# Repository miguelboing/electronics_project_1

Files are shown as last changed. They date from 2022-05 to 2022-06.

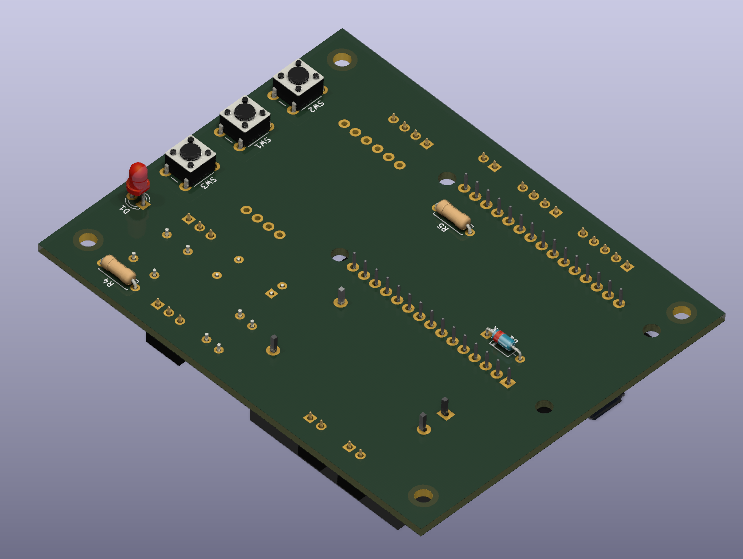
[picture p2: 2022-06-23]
hardware/botton_photo.png

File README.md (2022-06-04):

# _Electronics Project 1_

This project was created for the discipline EEL7801 - Dept. Electrical and Electronics Engineering.
The **Automatic Pet Feeder** was created to automate the routine of feeding your dog. It's hardware contains
a microcontroller ESP32 responsible for creating a routine of automatic feeding from a user configured time interval.

The firmware project uses the [ESPRESSIF framework](https://www.espressif.com/en/products/modules/esp32)
and all its tools.

## Firmware description

## Hardware description

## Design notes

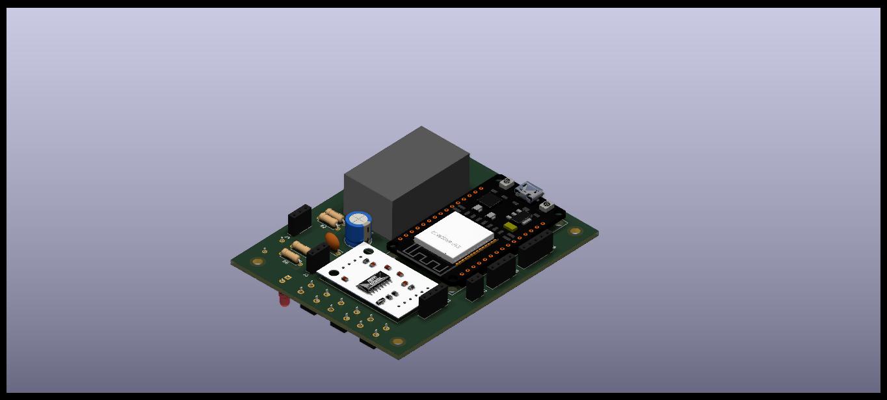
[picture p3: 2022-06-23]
hardware/alimentador automatico para pets.jpg

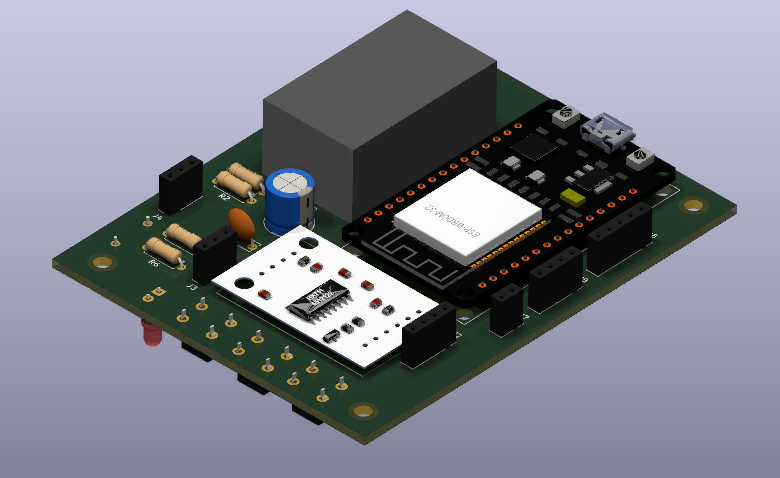
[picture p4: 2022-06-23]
hardware/top_photo.png

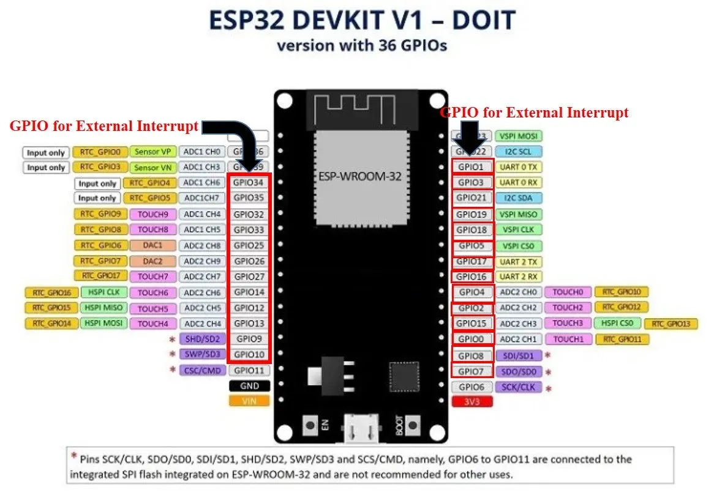
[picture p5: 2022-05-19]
documentation/ESP32-Interrupt-pins.webp

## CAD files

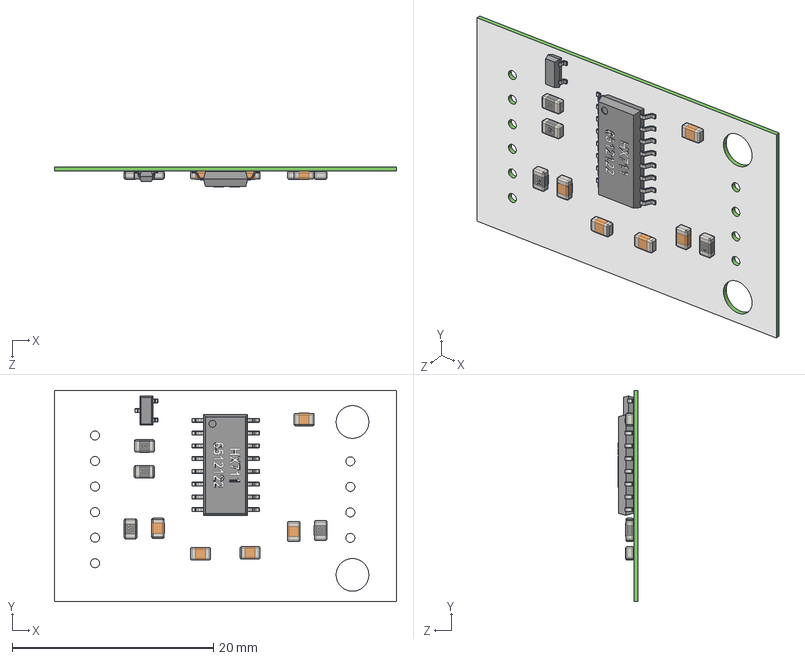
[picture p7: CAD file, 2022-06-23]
hardware/3d_models/HX711.STEP
34.0 x 21.0 x 1.97 mm
placa_Valor predeterminado
base_HX711_Valor predeterminado
pino_HX711_Valor predeterminado x 16
RESISTOR_SMD_122_Valor predeterminado x 2
RESISTOR_SMD_822_Valor predeterminado
RESISTOR_SMD_203_Valor predeterminado
CAPACITOR_805_Valor predeterminado x 5
TRANSISTOR_SOT23_Valor predeterminado
PINO_SOT23_Valor predeterminado x 3

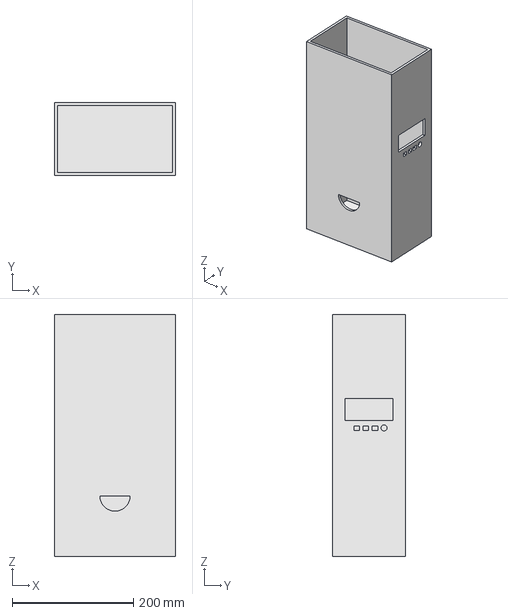
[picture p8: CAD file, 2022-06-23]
structure_model/Projeto_Alimentador3.0.FCStd
200.0 x 120.0 x 400.0 mm

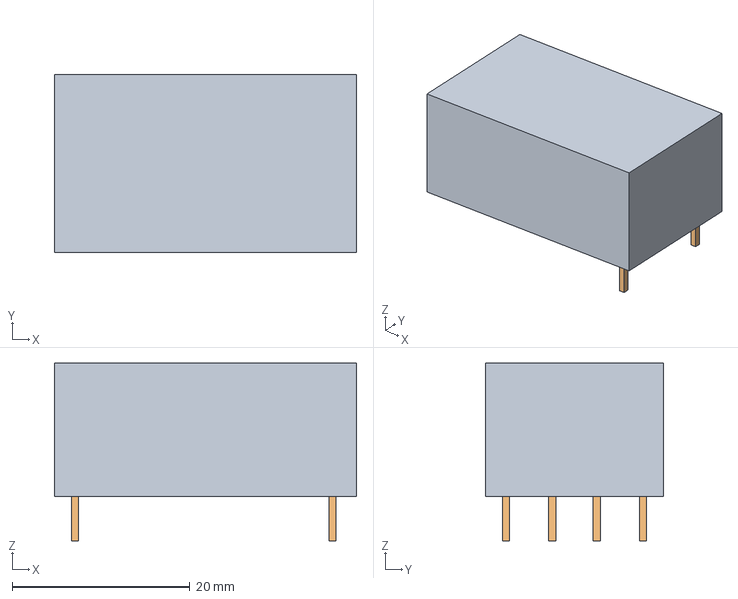
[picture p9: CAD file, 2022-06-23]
hardware/3d_models/HI-LINK HLK-PM01 3W 5VDC v1.step
34.0 x 20.0 x 20.0 mm

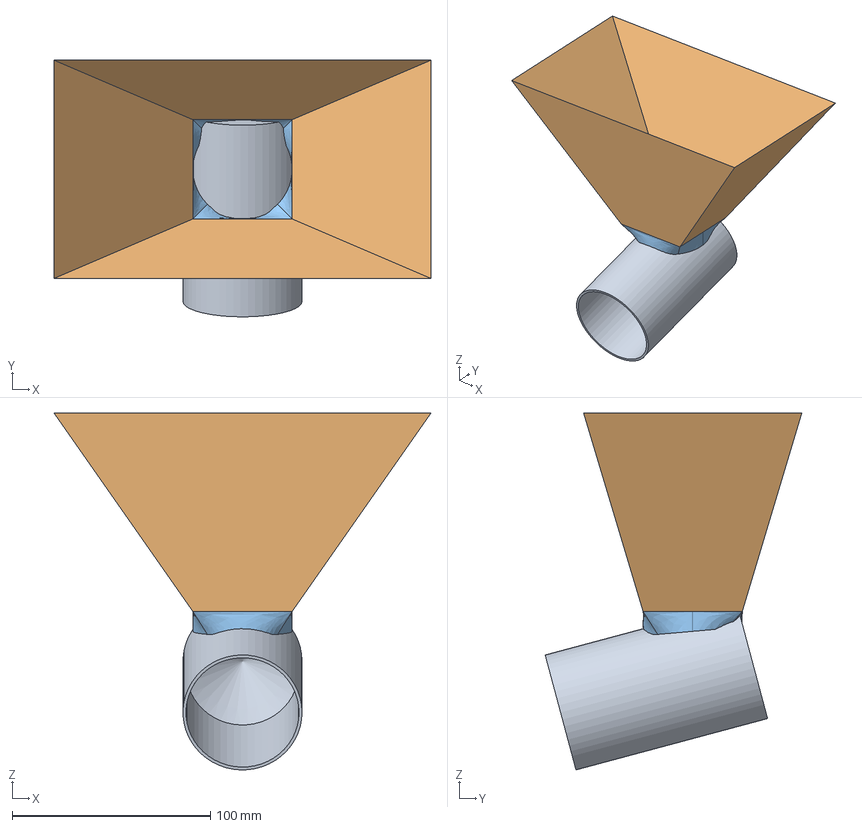
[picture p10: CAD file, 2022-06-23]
structure_model/Funil base quadrada ligado a base redonda+ligaçao.FCStd
190.0 x 129.4 x 179.8 mm

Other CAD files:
structure_model/structure_model.FCStd

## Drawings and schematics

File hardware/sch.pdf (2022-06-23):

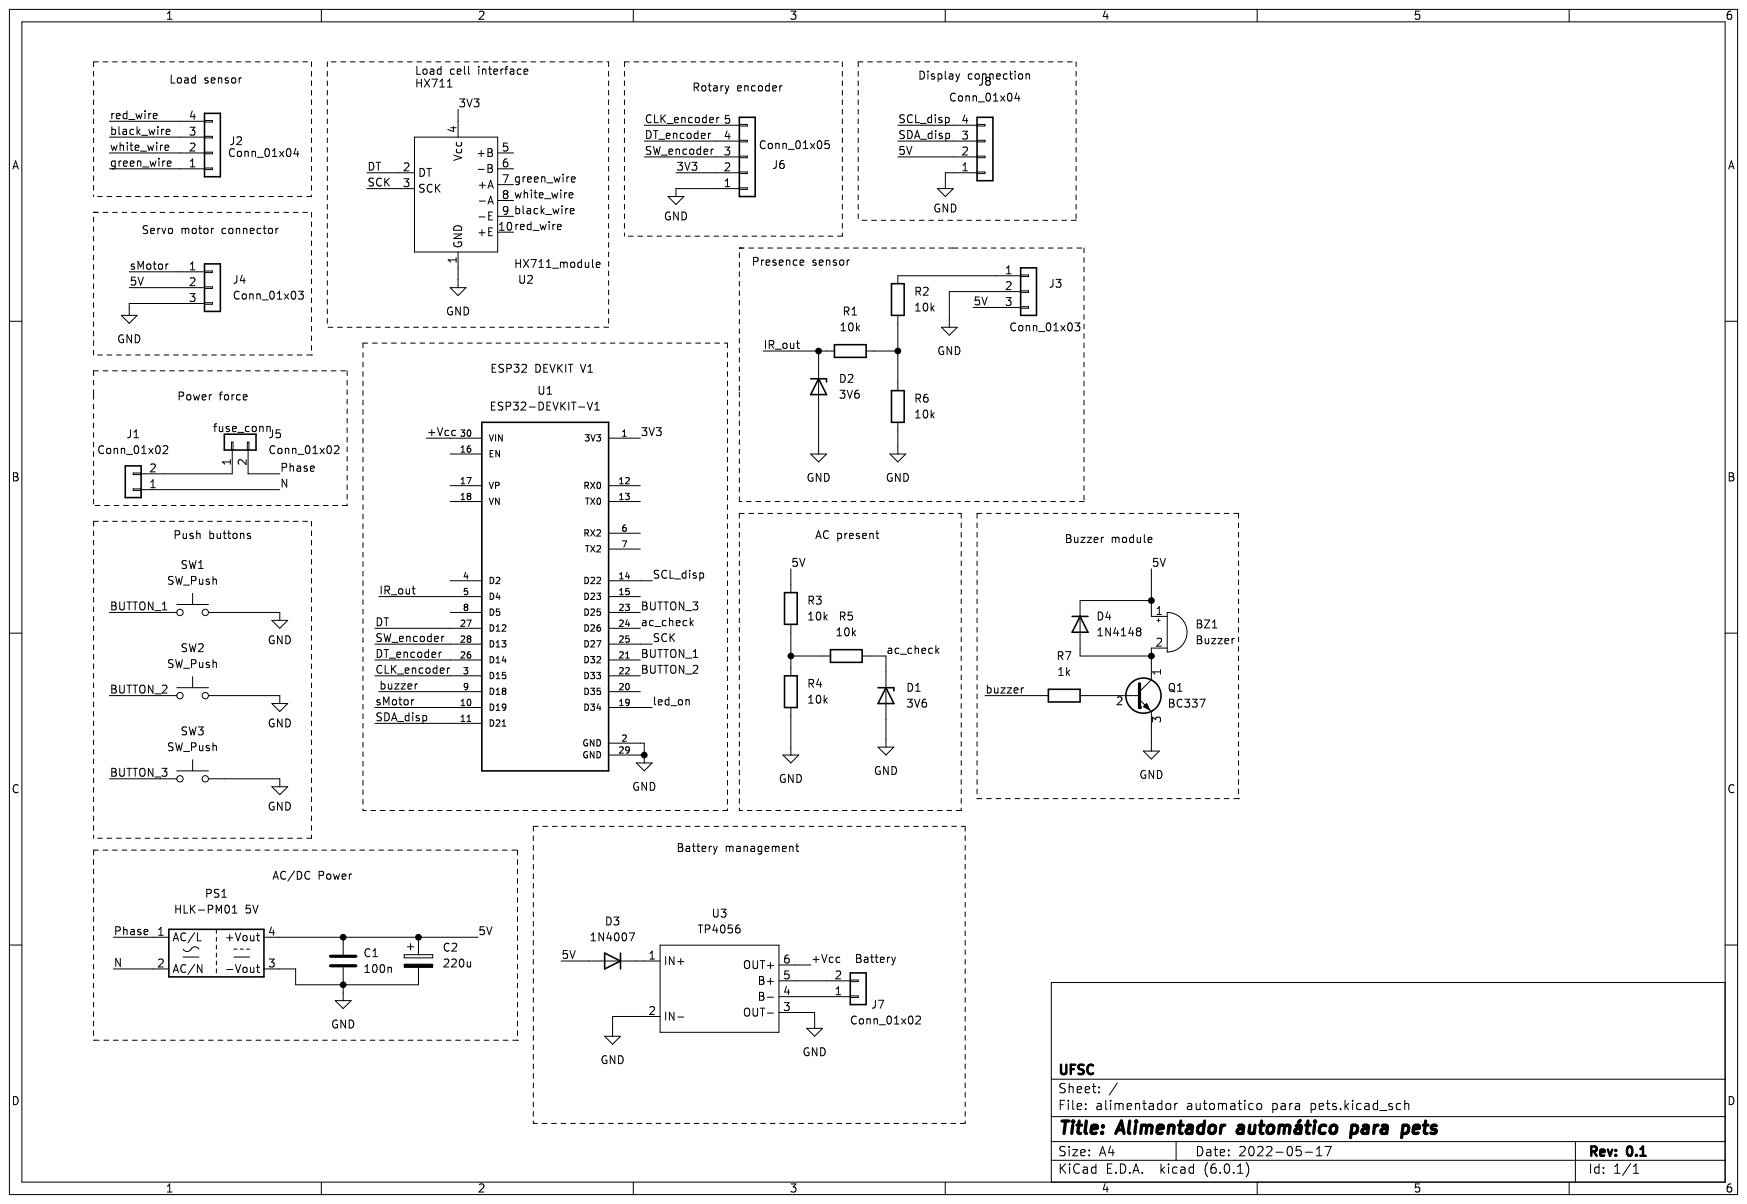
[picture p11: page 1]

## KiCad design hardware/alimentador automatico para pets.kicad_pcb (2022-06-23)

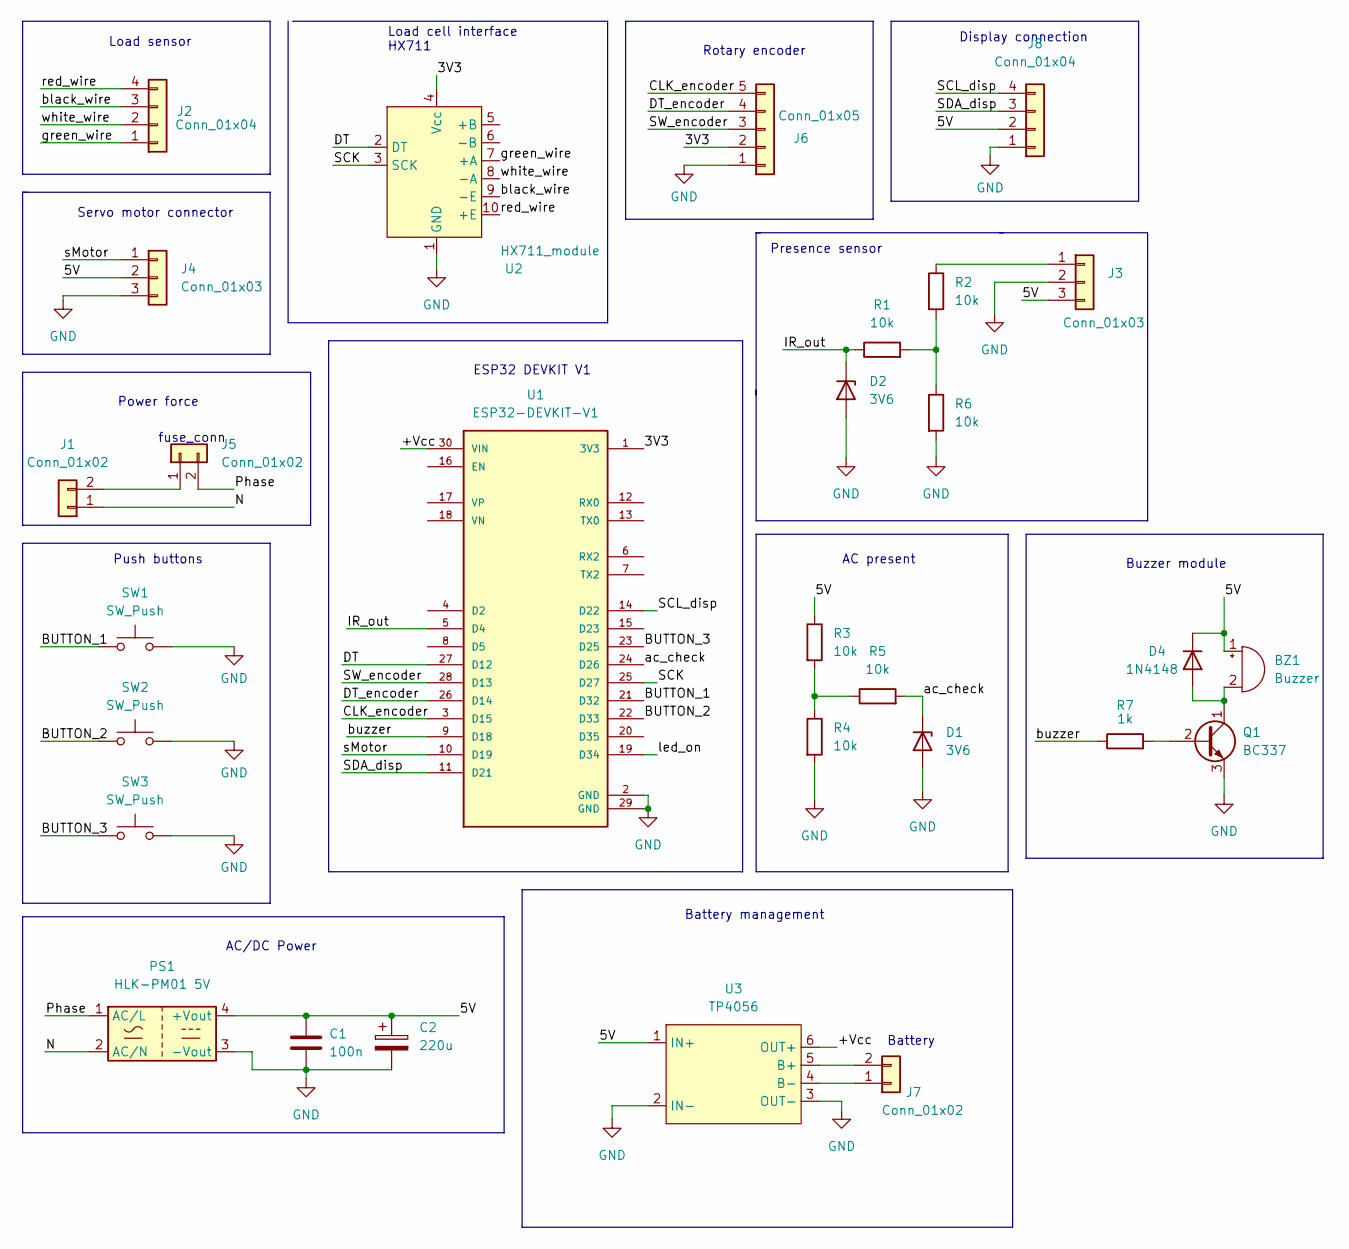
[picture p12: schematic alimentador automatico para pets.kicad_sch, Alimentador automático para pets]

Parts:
BZ1: Buzzer; Buzzer_TDK_PS1240P02BT_D12.2mm_H6.5mm
C1: 100n; C_Disc_D6.0mm_W2.5mm_P5.00mm
C2: 220u; CP_Radial_D8.0mm_P2.50mm
D1, D2: 3V6; D_DO-35_SOD27_P7.62mm_Horizontal
D4: 1N4148; D_DO-35_SOD27_P7.62mm_Horizontal
J1, J7: Conn_01x02; SolderWire-0.1sqmm_1x02_P3.6mm_D0.4mm_OD1mm_Relief
J2: Conn_01x04; SolderWire-0.1sqmm_1x04_P3.6mm_D0.4mm_OD1mm_Relief
J3: Conn_01x03; PinSocket_1x03_P2.54mm_Vertical
J4: Conn_01x03; PinHeader_1x03_P2.54mm_Vertical
J5: Conn_01x02; SolderWire-0.1sqmm_1x02_P3.6mm_D0.4mm_OD1mm
J6: Conn_01x05; PinSocket_1x05_P2.54mm_Vertical
J8: Conn_01x04; PinSocket_1x04_P2.54mm_Vertical
PS1: HLK-PM01 5V; Converter_ACDC_HiLink_HLK-PMxx
Q1: BC337; TO-92L_Inline_Wide
R1, R2, R3, R4, R5, R6: 10k; R_Axial_DIN0207_L6.3mm_D2.5mm_P7.62mm_Horizontal
R7: 1k; R_Axial_DIN0207_L6.3mm_D2.5mm_P7.62mm_Horizontal
SW1, SW2, SW3: SW_Push; SW_PUSH_6mm
U1: ESP32-DEVKIT-V1; MODULE_ESP32_DEVKIT_V1; PARTREV N/A
U2: HX711_module
U3: TP4056

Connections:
/3V3: J6.2, U1.1 (3V3), U2.4 (Vcc)
/5V: BZ1.1 (-), C1.1, C2.1, D4.1 (K), J3.3, J4.2, J8.2, PS1.4 (+Vout), R3.1, U3.1 (IN+)
/+Vcc: U1.30 (VIN), U3.6 (OUT+)
/BUTTON_1: SW1.1, U1.21 (D32)
/BUTTON_2: SW2.1, U1.22 (D33)
/BUTTON_3: SW3.1, U1.23 (D25)
/CLK_encoder: J6.5, U1.3 (D15)
/DT: U1.27 (D12), U2.2 (DT)
/DT_encoder: J6.4, U1.26 (D14)
/IR_out: D2.1 (K), R1.1, U1.5 (D4)
/N: J1.1, PS1.2 (AC/N)
/Phase: J5.2, PS1.1 (AC/L)
/SCK: U1.25 (D27), U2.3 (SCK)
/SCL_disp: J8.4, U1.14 (D22)
/SDA_disp: J8.3, U1.11 (D21)
/SW_encoder: J6.3, U1.28 (D13)
/ac_check: D1.1 (K), R5.2, U1.24 (D26)
/black_wire: J2.3, U2.9 (-E)
/buzzer: R7.1, U1.9 (D18)
/green_wire: J2.1, U2.7 (+A)
/led_on: U1.19 (D34)
/red_wire: J2.4, U2.10 (+E)
/sMotor: J4.1, U1.10 (D19)
/white_wire: J2.2, U2.8 (-A)
GND: C1.2, C2.2, D1.2 (A), D2.2 (A), J3.2, J4.3, J6.1, J8.1, PS1.3 (-Vout), Q1.3 (E), R4.2, R6.2, SW1.2, SW2.2, SW3.2, U1.2 (GND), U1.29 (GND), U2.1 (GND), U3.2 (IN-), U3.3 (OUT-)
unnamed: BZ1.2 (+), D4.2 (A), Q1.1 (C)
unnamed: J1.2, J5.1
unnamed: J3.1, R2.1
unnamed: J7.1, U3.4 (B-)
unnamed: J7.2, U3.5 (B+)
unnamed: Q1.2 (B), R7.2
unnamed: R1.2, R2.2, R6.1
unnamed: R3.2, R4.1, R5.1

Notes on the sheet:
AC/DC Power
Rotary encoder
Buzzer module
Battery
Load sensor
Presence sensor
Load cell interface HX711
ESP32 DEVKIT V1
Display connection
AC present
Power force
Battery management
Push buttons
fuse_conn
Servo motor connector

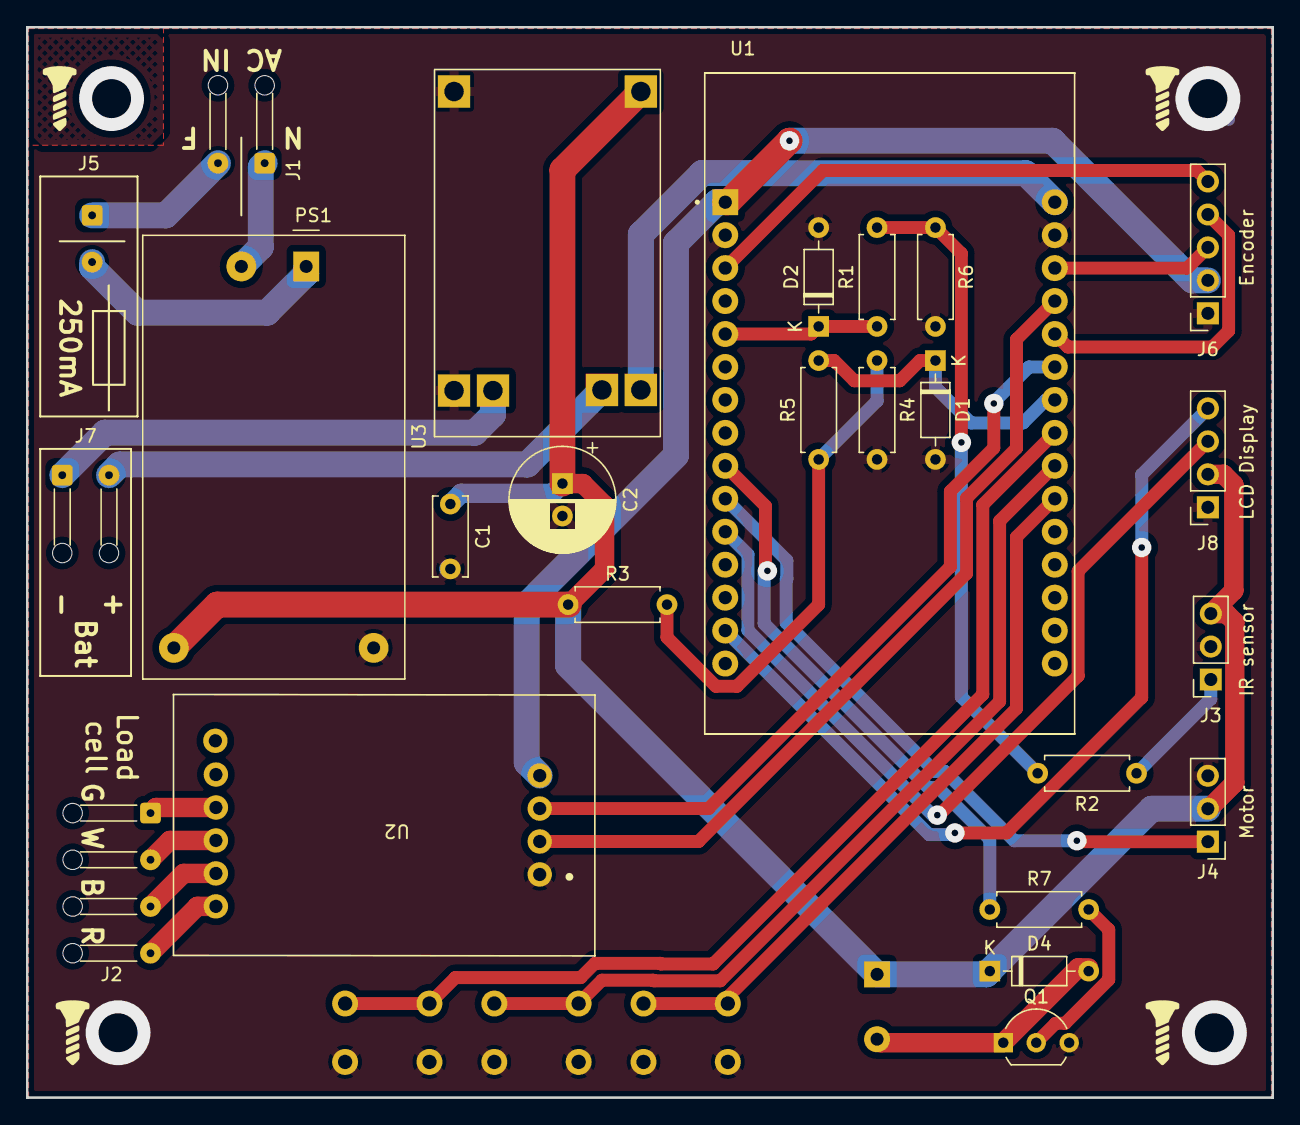
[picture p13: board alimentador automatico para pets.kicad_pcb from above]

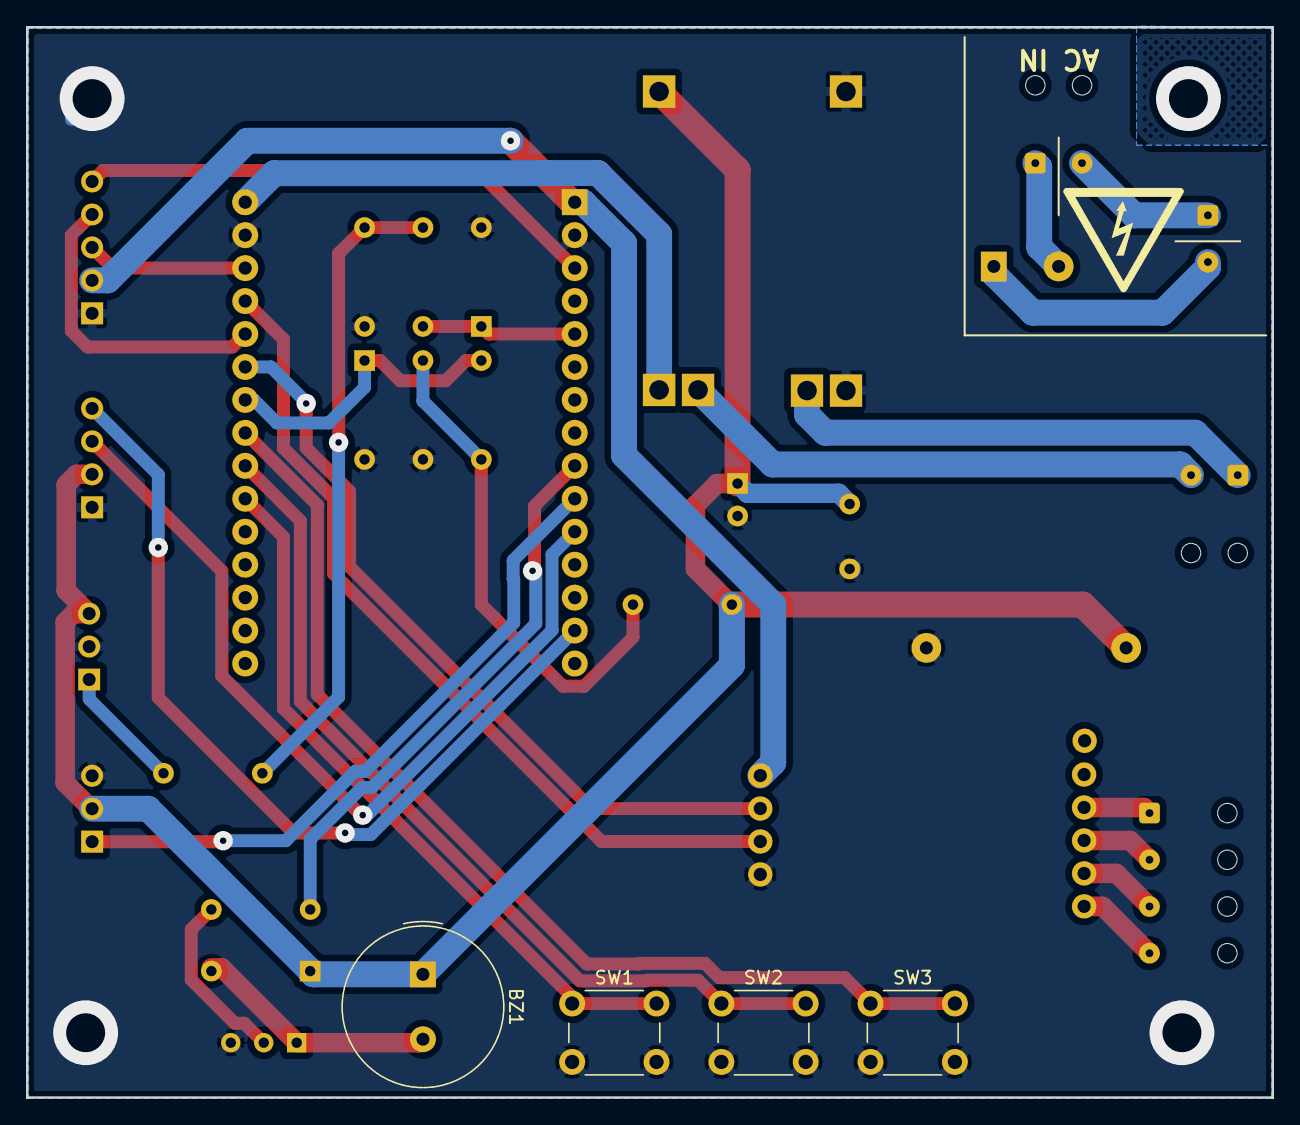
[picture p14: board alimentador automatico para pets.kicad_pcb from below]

Board: 2 copper layers, 96.0 x 82.5 mm, 29 parts (4 on the bottom side), 32 nets.

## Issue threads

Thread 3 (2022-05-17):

Create all symbols for schematic

MarceloMCardoso, 2022-05-17:
# Symbols for schematic
- microprocessor
- IR sensor
- servo motor connector
- HX711 module
- load sensor
- encoder connector
- display connector

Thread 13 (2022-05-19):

Mechanical modeling feed release device

MarceloMCardoso, 2022-05-19:
# Mechanical modeling feed release device
1. definition of general operation
2. adding servo motor model
3. preliminary modeling
4. review and simulation test

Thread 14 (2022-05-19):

Creat all components footprints

MarceloMCardoso, 2022-05-19:
# Creat all components footprints
1. ESP32
2. push buttons
3. connectors
4. power system
5. fuse
6. others

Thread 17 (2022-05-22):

Change pin on the schematics

ecocaval, 2022-05-22:
I had problems with the internal pull-up resistor in pin 35 (SW3). In my code i used pin D27 that is occupied by HX711 in our schematics.

Closed 2022-05-24.

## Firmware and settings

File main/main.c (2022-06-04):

#include <stdio.h>

#include "esp_system.h"
#include "sdkconfig.h"

#include "freertos/FreeRTOS.h"
#include "freertos/task.h"

#include "esp_log.h"

#include "driver/gpio.h"

/*Drivers */
#include "devices/buttons/buttons.h"
#include "devices/display_LCD/display_LCD.h"
#include "devices/encoder/encoder.h"

void app_main(void)
{
	char *ourTaskName = pcTaskGetName(NULL);
	ESP_LOGI(ourTaskName, "Hello, starting up!\n");

	gpio_reset_pin(BLINK_LED);
	gpio_set_direction(BLINK_LED, GPIO_MODE_OUTPUT);

	while (1)
	{
        Blink_lEDS();
	}
}

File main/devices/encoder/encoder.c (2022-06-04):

/*
 * encoder.c
 *
 *  Created on: 26/05/2022
 *
 */

#include "freertos/FreeRTOS.h"
#include "freertos/task.h"

#include "driver/gpio.h"
#include "encoder.h"

void clk_encoder_init(clk_encoder_e encod)
{
    gpio_config_t clk_encoder_gpio = {};  
    clk_encoder_gpio.intr_type = GPIO_INTR_ANYEDGE; 
    clk_encoder_gpio.mode = GPIO_MODE_INPUT; 
    clk_encoder_gpio.pull_up_en = GPIO_PULLUP_DISABLE; 
    clk_encoder_gpio.pull_down_en = GPIO_PULLDOWN_DISABLE;  
    clk_encoder_gpio.pin_bit_mask = (1ULL << encod); 

    if (gpio_config(&clk_encoder_gpio) == ESP_OK) printf("Successfully configured CLK_encoder!\n");  
    else printf("CLK_encoder was not configured sucessfully\n"); 
}

void dt_encoder_init(dt_encoder_e encod)
{
    gpio_config_t dt_encoder_gpio = {};  
    dt_encoder_gpio.intr_type = GPIO_INTR_DISABLE; 
    dt_encoder_gpio.mode = GPIO_MODE_INPUT; 
    dt_encoder_gpio.pull_up_en = GPIO_PULLUP_DISABLE; 
    dt_encoder_gpio.pull_down_en = GPIO_PULLDOWN_DISABLE;  
    dt_encoder_gpio.pin_bit_mask = (1ULL << encod); 

    if (gpio_config(&dt_encoder_gpio) == ESP_OK) printf("Successfully configured DT_encoder!\n");  
    else printf("DT_encoder was not configured sucessfully\n"); 
}

void sw_encoder_init(sw_encoder_e encod)
{
    gpio_config_t sw_encoder_gpio = {};  
    sw_encoder_gpio.intr_type = GPIO_INTR_NEGEDGE; 
    sw_encoder_gpio.mode = GPIO_MODE_INPUT; 
    sw_encoder_gpio.pull_up_en = GPIO_PULLUP_ENABLE; 
    sw_encoder_gpio.pull_down_en = GPIO_PULLDOWN_DISABLE; 
    sw_encoder_gpio.pin_bit_mask = (1ULL << encod); 
    
    if (gpio_config(&sw_encoder_gpio) == ESP_OK) printf("Successfully configured SW_encoder!\n");  
    else printf("SW_encoder was not configured sucessfully\n"); 
}

int verify_clk_encoder_level(clk_encoder_e encod) {return gpio_get_level(encod);}
int verify_dt_encoder_level(dt_encoder_e encod) {return gpio_get_level(encod);}

// ISR + TASK for SW_encoder;
void IRAM_ATTR sw_encoder_isr_handler(void* param) {xTaskResumeFromISR(task_handle_sw_encoder);}

void task_sw_encoder(void* param)
{
	sw_encoder_init(SW_encoder);

   	gpio_isr_handler_add(SW_encoder, sw_encoder_isr_handler, NULL);

	while (1)
	{
		vTaskSuspend(NULL);
		// confirm food quantity counter value;
		vTaskDelay(pdMS_TO_TICKS(250));
	}
}

// ISR + TASK for CLK_encoder and DT_encoder;
void IRAM_ATTR rotation_encoder_isr_handler(void* param) {xTaskResumeFromISR(task_handle_rotation_encoder);}

void task_rotation_encoder(void* param)
{	
	clk_encoder_init(CLK_encoder); 
	dt_encoder_init(DT_encoder);

   	gpio_isr_handler_add(CLK_encoder, rotation_encoder_isr_handler, NULL);

	int present_state_CLK_encoder;
    	int present_state_DT_encoder;
    	int food_quantity_counter = 0;

	while (1)
	{
		vTaskSuspend(NULL);

		present_state_CLK_encoder = verify_clk_encoder_level(CLK_encoder);
		present_state_DT_encoder = verify_clk_encoder_level(DT_encoder);

		if (present_state_CLK_encoder != present_state_DT_encoder) 
		{
		    food_quantity_counter++;
		    vTaskDelay(pdMS_TO_TICKS(10));
		}
		else 
		{
		    food_quantity_counter--;
		    vTaskDelay(pdMS_TO_TICKS(10));
		}    
	}
}

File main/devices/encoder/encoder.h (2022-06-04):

/*
 * encoder.h
 *
 *  Created on: 26/05/2022
 *
 */

#ifndef ENCODER_H_
#define ENCODER_H_

typedef enum{CLK_encoder = GPIO_NUM_15} clk_encoder_e;
typedef enum{DT_encoder = GPIO_NUM_14} dt_encoder_e;
typedef enum{SW_encoder = GPIO_NUM_13} sw_encoder_e;

TaskHandle_t task_handle_sw_encoder = NULL;
TaskHandle_t task_handle_rotation_encoder = NULL;

void clk_encoder_init(clk_encoder_e encod);
void dt_encoder_init(dt_encoder_e encod);
void sw_encoder_init(sw_encoder_e encod);

int verify_clk_encoder_level(clk_encoder_e encod);
int verify_dt_encoder_level(dt_encoder_e encod);

void task_sw_encoder(void* param);
void task_rotation_encoder(void* param);

#endif /* ENCODER_H_ */

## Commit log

2022-05-06 Added sample project
2022-05-08 Adding Esp32 documentation
2022-05-16 Initial hardware files
    [alimentador automatico para pets.kicad_pcb, alimentador automatico para pets.kicad_sch]
2022-05-17 Added all symbols closed #3
    [alimentador automatico para pets.kicad_sch]
2022-05-17 schematic organization update
2022-05-17 create model files
    [structure_model.FCStd]
2022-05-18 Implementing initial blink led example
2022-05-18 Creating device files
2022-05-19 pins with external interrupt
2022-05-19 add push buttons to shcematic
    [alimentador automatico para pets.kicad_sch]
2022-05-19 add references to push buttons and resistors
    [alimentador automatico para pets.kicad_sch]
2022-05-19 Added function definitions for buttons #4
2022-05-20 Proximity sensor function declarations and definitions #8
2022-05-20 Working functions for proximity sensor resolves #8
    [proximity_sensor.c]
2022-05-21 Modified presence sensor pin and voltage closed #15
    [alimentador automatico para pets.kicad_sch]
2022-05-22 Comittando a funcao feita para os buttons (há um exemplo de funcionamento no main.c)
2022-05-22 Update main.c
    Corrigindo indentação
    [main.c]
2022-05-22 Update buttons.c
    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
    [buttons.c]
2022-05-24 change labels and pins for buttons closed #17
    [alimentador automatico para pets.kicad_sch]
2022-05-25 add new theme in kicad vizualization
2022-05-26 rearrange schematic
    [alimentador automatico para pets.kicad_sch]
2022-05-27 Including IoT lib to handle servo motor #6
2022-05-27 Servo motor device resolves #6
    [servo_motor.c]
2022-05-30 closes #2, closes #4; Working functions for buttons and encoder
2022-06-01 pcb design start
    [HI-LINK HLK-PM01 3W 5VDC v1.step, HX711.STEP, alimentador automatico para pets.kicad_pcb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]
2022-06-02 removing leds and changing components positions #14
    [alimentador automatico para pets.kicad_pcb, alimentador automatico para pets.kicad_sch]
2022-06-03 add battery module
    [alimentador automatico para pets.kicad_pcb, alimentador automatico para pets.kicad_sch]
2022-06-04 att schematic #14
    [alimentador automatico para pets.kicad_pcb, alimentador automatico para pets.kicad_sch]
2022-06-04 Updating buttons and encoder functions
2022-06-04 Improving encoder.c indentation
2022-06-07 added buzzer #21
    [alimentador automatico para pets.kicad_pcb, alimentador automatico para pets.kicad_sch]
2022-06-08 add 3d models pins #14
    [alimentador automatico para pets.kicad_pcb]
2022-06-09 place components and board roadmap #22
    [alimentador automatico para pets.kicad_pcb, alimentador automatico para pets.kicad_sch]
2022-06-09 pcb design review
    [alimentador automatico para pets-B_Cu.gbr, alimentador automatico para pets-B_Mask.gbr, alimentador automatico para pets-B_Paste.gbr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]
2022-06-23 add gerber files closed #22
    [Funil base quadrada ligado a base redonda+ligaçao.FCStd, Projeto_Alimentador3.0.FCStd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]
